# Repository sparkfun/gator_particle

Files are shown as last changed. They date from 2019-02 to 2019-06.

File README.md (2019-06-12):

SparkFun gator:particle - micro:bit Accessory Board
=============================

SparkFun gator:particle - micro:bit Accessory Board

[*SparkFun gator:particle - micro:bit Accessory Board (SEN-15271)*](https://www.sparkfun.com/products/15271)

An I<sup>2</sup>C sensor for detecting particles. Additionaly, the MAX30102 sensor can also be used for measure heart-rate and SpO<sub>2</sub> using special algorithms. These algorithms have limited functionality and are primarily meant for demonstration purposed.

*Example of pulse measurement:*
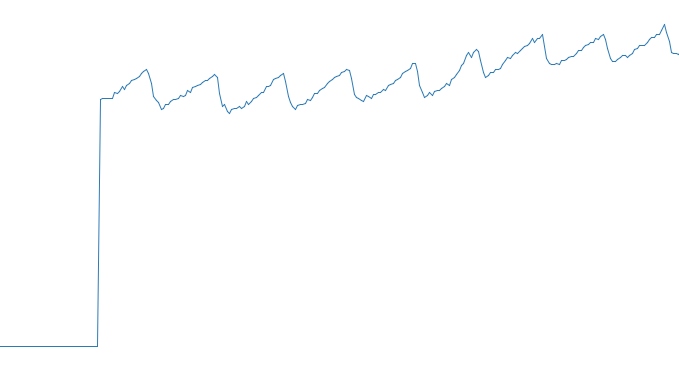
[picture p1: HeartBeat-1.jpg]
Pulse Graph


Instead of using pin connections or requiring soldering, this product provides connection pads for a more kid freindly experience with alligator clips. The design intention of this product is to be used with the [gato:bit (v2)](https://www.sparkfun.com/products/15162), and the [micro:bit development board](https://www.sparkfun.com/products/14208).

Repository Contents
-------------------

* **/Hardware** - Eagle design files (.brd, .sch)
* **/Production** - Production panel files (.brd)

Documentation
--------------
* **[Hookup Guide](https://learn.sparkfun.com/tutorials/sparkfun-gatorparticle-hookup-guide)** - Basic hookup guide for the gator:particle.
* **[gator:particle PXT Package](https://github.com/sparkfun/pxt-gator-particle)** - PXT- package for the MakeCode gator:particle extension.

License Information
-------------------

This product is _**open source**_! 

Please review the LICENSE.md file for license information. 

If you have any questions or concerns on licensing, please visit the [SparkFun Forum](https://forum.sparkfun.com/index.php) and post a topic. For more general questions related to our gator boards, please visit this section of the forum: [Gator Products](https://forum.sparkfun.com/viewforum.php?f=162).

Distributed as-is; no warranty is given.

- Your friends at SparkFun.

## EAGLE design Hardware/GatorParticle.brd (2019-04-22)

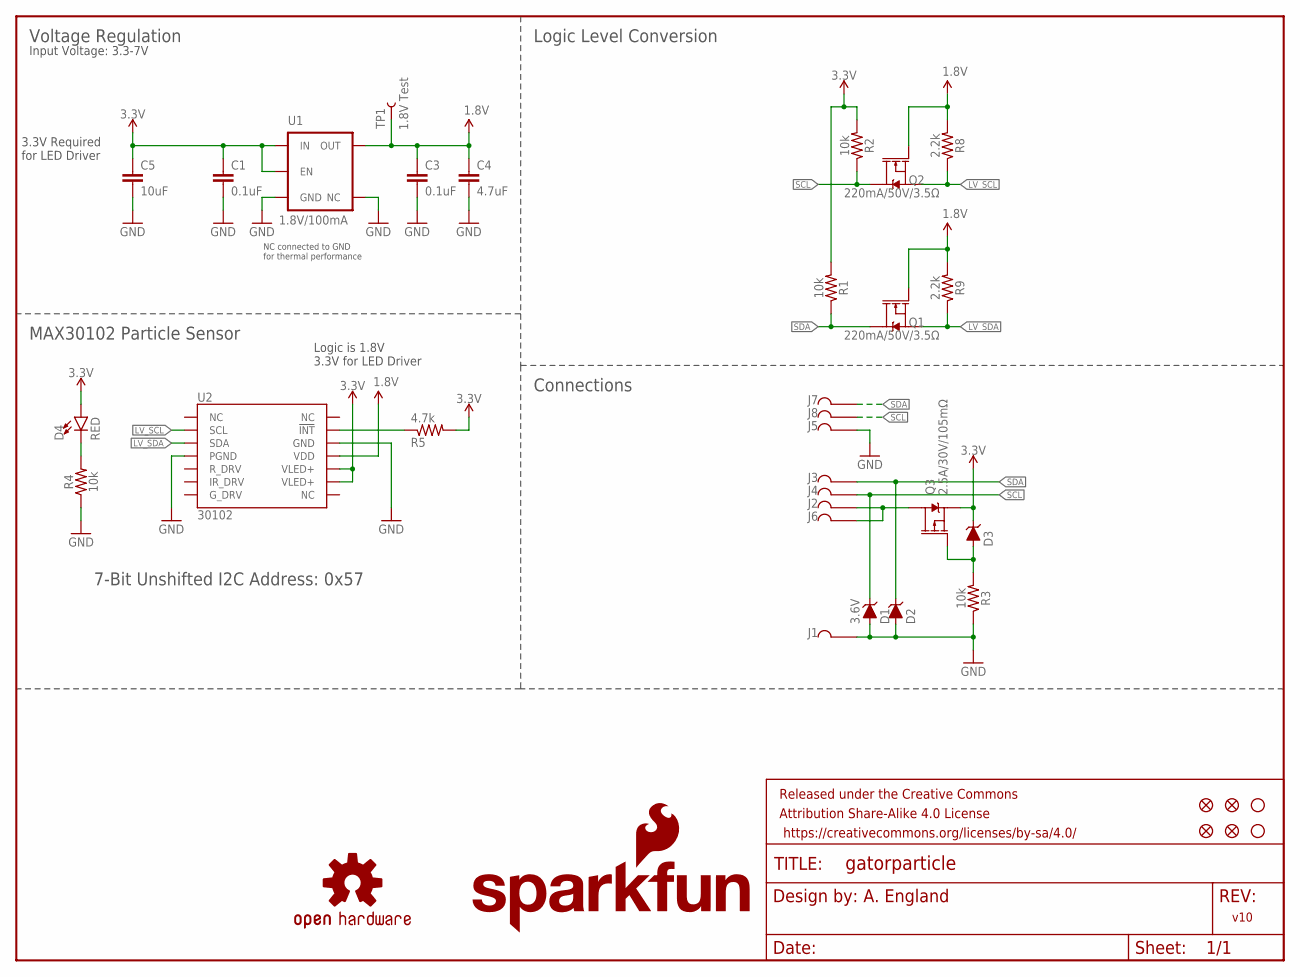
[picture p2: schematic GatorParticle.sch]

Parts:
C1, C3: 0.1uF; 0603
C4: 4.7uF; 0603
C5: 10uF; 0603
D1, D2, D3: 3.6V; SOD-323
D4: RED; LED-0603
FID1, FID2, FID3, FID4: FIDUCIALUFIDUCIAL; FIDUCIAL-MICRO
FRAME1: FRAME-LETTER; CREATIVE_COMMONS
J1, J2, J3, J4, J5, J6, J7, J8: GATORGATOR_MINI; GATOR_MINI
LOGO1: SFE_LOGO_NAME_FLAME.1_INCH; SFE_LOGO_NAME_FLAME_.1
LOGO2: OSHW-LOGOS; OSHW-LOGO-S
Q1, Q2: 220mA/50V/3.5Ω; SOT23-3
Q3: 2.5A/30V/105mΩ; SOT23-3
R1, R2, R3, R4: 10k; 0603
R5: 4.7k; 0603
R8, R9: 2.2k; 0603
STANDOFF2, STANDOFF3: STAND-OFFTIGHT; STAND-OFF-TIGHT
TP1: 1.8V Test; PAD.03X.04
U1: 1.8V/100mA; SC70
U2: 30102; OLGA-14

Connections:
1.8V: C3.1, C4.1, Q1.1 (G), Q2.1 (G), R8.2, R9.2, TP1.P$1, U1.5 (OUT), U2.11 (VDD)
3.3V: C1.1, C5.1, D3.C, D4.A, Q3.2 (S), R1.2, R2.2, R5.2, U1.1 (IN), U1.3 (EN), U2.9 (VLED+), U2.10 (VLED+)
!INT: R5.1, U2.13 (!INT)
GND: C1.2, C3.2, C4.2, C5.2, D1.A, D2.A, J1.P$2, J5.P$2, R3.1, R4.1, U1.2 (GND), U1.4 (NC), U2.4 (PGND), U2.12 (GND)
LV_SCL: Q2.2 (S), R8.1, U2.2 (SCL)
LV_SDA: Q1.2 (S), R9.1, U2.3 (SDA)
unnamed: D3.A, Q3.1 (G), R3.2
unnamed: J2.P$2, J6.P$2, Q3.3 (D)
unnamed: D4.C, R4.2
SCL: D1.C, J4.P$2, J8.P$2, Q2.3 (D), R2.1
SDA: D2.C, J3.P$2, J7.P$2, Q1.3 (D), R1.1

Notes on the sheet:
7-Bit Unshifted I2C Address: 0x57
v10
A. England
Voltage Regulation
Connections
MAX30102 Particle Sensor
3.3V Required for LED Driver
Logic is 1.8V 3.3V for LED Driver
NC connected to GND for thermal performance
Input Voltage: 3.3-7V
Logic Level Conversion

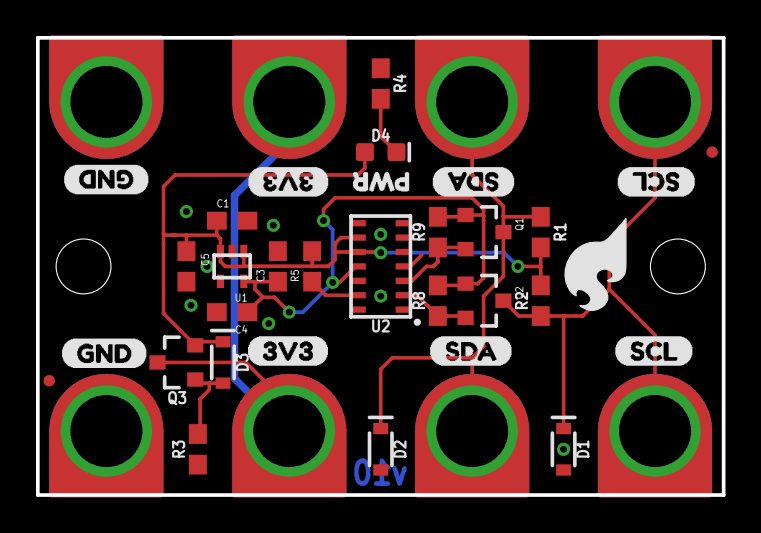
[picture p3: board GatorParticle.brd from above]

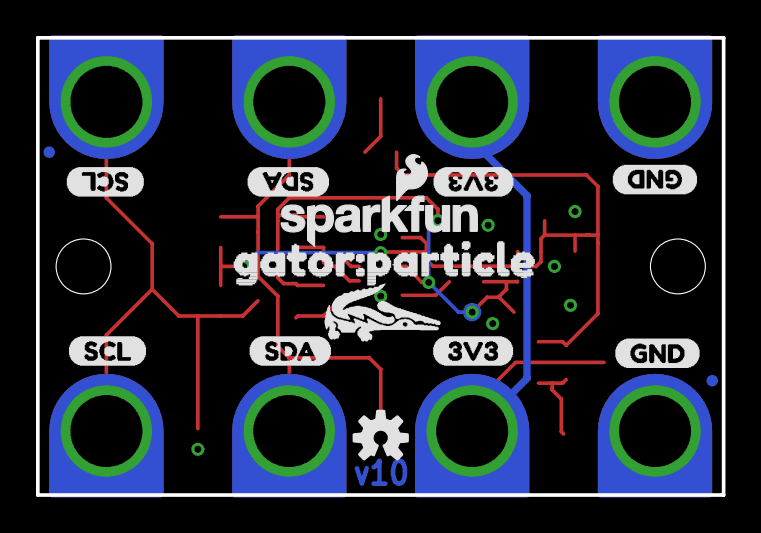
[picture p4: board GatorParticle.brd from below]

Board: 2 copper layers, 38.1 x 25.4 mm, 59 parts (15 on the bottom side), 11 nets.

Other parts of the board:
U$1, U$5, U$9, U$13: GND0
U$2, U$6, U$10, U$14: 3V33
U$3, U$7, U$11, U$15: SDA2
U$4, U$8, U$12, U$16: SCL1
U$17: SFE_LOGO_FLAME_.2
U$18: ORDERING_INSTRUCTIONS
U$19: PWR0
U$21: GATORBIT_FINAL_FOR_SILK#01#PNG
U$22: GATOR#PARTICLE0

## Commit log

2019-02-25 inital commit
    [MAX30105_Breakout.brd, MAX30105_Breakout.sch]
2019-02-27 adding silk labelling
    [MAX30105_Breakout.brd, MAX30105_Breakout.sch]
2019-02-28 adding protection circuitry
    [MAX30105_Breakout.brd, MAX30105_Breakout.sch]
2019-02-28 finalizing silk and schematic before design review
    [MAX30105_Breakout.brd, MAX30105_Breakout.sch]
2019-03-01 engineer run of checklist
    [Board_Design_Checklist_gatorparticle_v01.xls, MAX30105_Breakout.brd, MAX30105_Breakout.sch]
2019-03-01 forgot to save changes from review/checklist
    [MAX30105_Breakout.brd, MAX30105_Breakout.sch]
2019-03-12 Post checklist changes
    [GatorParticle.brd, GatorParticle.sch]
2019-04-16 pre design review reds
    [GatorParticle.GBL, GatorParticle.GBO, GatorParticle.GBS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]
2019-04-22 qc double check changes
    [GatorParticle.brd]
2019-06-12 Update to current product information
    Will need to update forum link and description
2019-06-14 cleaning repo
    [Board_Design_Checklist_gatorparticle_v01.xls]

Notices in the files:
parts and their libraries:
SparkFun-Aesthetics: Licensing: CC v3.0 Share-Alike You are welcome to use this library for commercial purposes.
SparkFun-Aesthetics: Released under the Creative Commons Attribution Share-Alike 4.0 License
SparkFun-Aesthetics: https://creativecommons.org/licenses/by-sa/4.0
